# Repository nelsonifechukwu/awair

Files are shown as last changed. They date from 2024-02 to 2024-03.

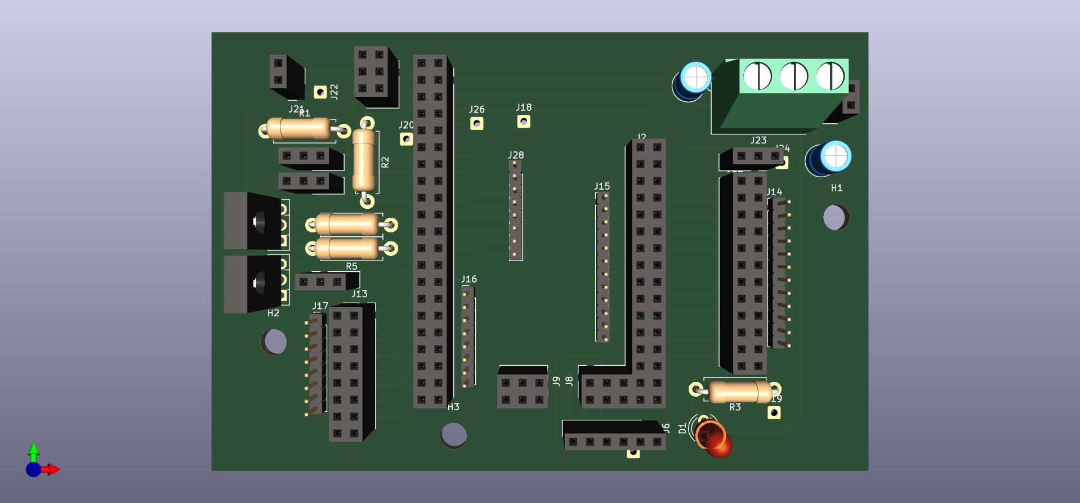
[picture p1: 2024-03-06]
Awair/CAD/Electrical Design/Awair.jpg

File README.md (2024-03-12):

# AWAIR

In Africa, the absence of an extensive meteorological device network has posed a significant challenge for environmental research, hindering accurate ground-truth data acquisition. This limitation affects various sectors, including government initiatives, urban planning, pollution control, etc.

Recognizing this gap, Awair emerges as a groundbreaking solution, offering an advanced, cloud-connected, real-time platform for environmental data. Awair aims to empower top universities, research labs, government agencies, and African industrial applications by providing accurate meteorological insights, facilitating informed decision-making, and sustainable solutions for environmental challenges.

Awair's data awareness, research, and analytics capabilities present a transformative approach to addressing the pressing issues related to the environment in the African context.



# Table of Content
- [Testing](#Testing)
  - [Input temperature data](#input-tph-data)
  - [Input airqo data](#input-airqo-data)
  - [Input wind data](#input-wind-data)
  - [Input location data](#input-location-data)
- [Hardware Design](#hardware-design)
  - [Electrical CAD](#electrical-cad)
  - [Mechanical CAD](#mechanical-cad)
  - [Embedded Software](#embedded-software)
 
# Testing 
- Register at [Awair](https://awair.onrender.com/)
- Create a Device using any of these ID:
<br> 
- Start [sending](#sending-data)  
- Go to the analytics section to view forecast and visualize your data

<h3> Sending Data </h3>
Your hardware should use the following endpoints to interact with the platform: 

### Input tph data

- **URL:** `/temp`
- **Method:** `POST`
- **Description:** Allows users to insert data.
- **Request Body:**
```
body request: {
    "uuid":"8254f02a-1c06-46f0-8382-66ad5be70cb6",
    "temperature": "20",
    "humidity":"50",
    "pressure": "80"
}
```

- **Response:**

```json
created
```

### Input airqo data

- **URL:** `/airqo`
- **Method:** `POST`
- **Description:** Allows users to insert data.
- **Request Body:**
```
body request: {
    "uuid":"8254f02a-1c06-46f0-8382-66ad5be70cb6",
    "pm2.5":"11.3",
    "pm10":"25",
    "co_index": 10
}
```

- **Response:**

```json
created
```

### Input wind data

- **URL:** `/wind`
- **Method:** `POST`
- **Description:** Allows users to insert data.
- **Request Body:**
```
body request: {
    "uuid": "8254f02a-1c06-46f0-8382-66ad5be70cb6",
    "wind-speed":"23",
    "wind-direction":"40"
}
```

- **Response:**

```json
created
```
### Input location data

- **URL:** `/location`
- **Method:** `POST`
- **Description:** Allows users to insert data.
- **Request Body:**
```
body request: {
    "uuid":"8254f02a-1c06-46f0-8382-66ad5be70cb6",
    "location": "0,40",
    "battery":"50",
    "signal": "80"
}
```

- **Response:**

```json
created
```

# Hardware Design
  <h3>Electrical CAD</h3> 
  
  <ins>Requirements: </ins>
  - Basic Electronics
  - Hardware Materials:
    - ESP32
    - SD Card Module & SD Card
    - Female Header Pins
    - DHT 22 Temperature Sensor
    - BMP180 Pressure Sensor
    - Sim 800l EVB GPS/GSM/GPRS sensor
    - CO2 sensor
    - Pm 2.5 & Pm 10 Air Quality Sensors
    - Batteries (4x 3.7v Lipo Batteries)
    - Wires
    - 2x 12-5v Buck Converters
     
 <ins>How To: </ins>
 - Download the CAD files from ```.Awair/CAD/Electrical Design```
 - Use a printing service like JLC PCB to print the PCB. Or, use a CNC to cut the designed sketch
 - Mount the parts as shown in the PCB Diagram.

<h3>Mechanical CAD</h3>

 <ins>Requirements: </ins>
 - Basic CAD skills
 - Basic 3d Printing
   
 <ins>How To: </ins>
 - Download the CAD files from ```.Awair/CAD/Mechanical Design```
 - Use a 3d printer to print the files (battery pack, cover, enclosure).

<h3>Embedded Software</h3>

<ins>How To:</ins>
 - After setting up the hardware, open the file ```Awair/Embedded Code``` using platformIDE
 - Edit your variable ```uuid``` with the uuid obtained after registration
 - Edit the variable ```API-key``` with the API-Key obtained from the web application after registration
 - Upload the code to the ESP32

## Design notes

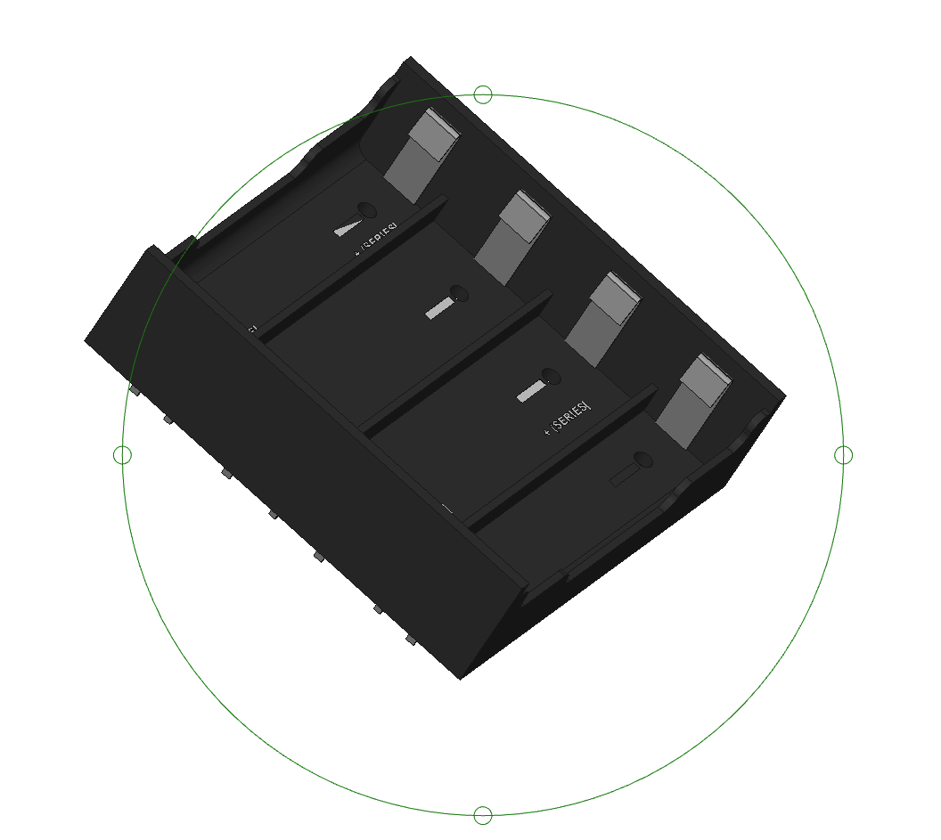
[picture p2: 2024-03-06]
Awair/CAD/Mechanical Design/Battery Pack.png

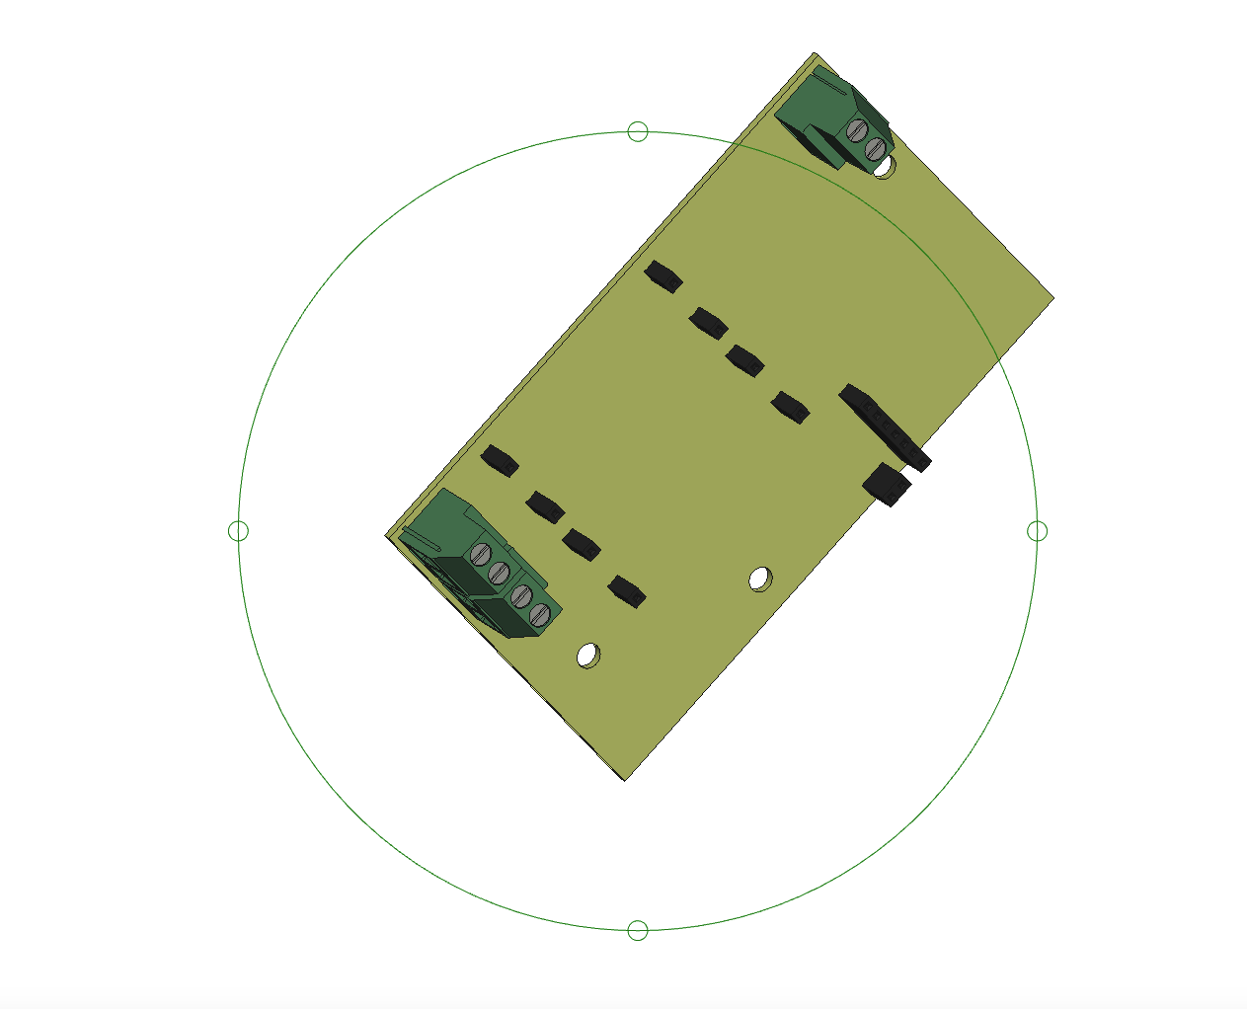
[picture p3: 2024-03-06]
Awair/CAD/Mechanical Design/PDB.png

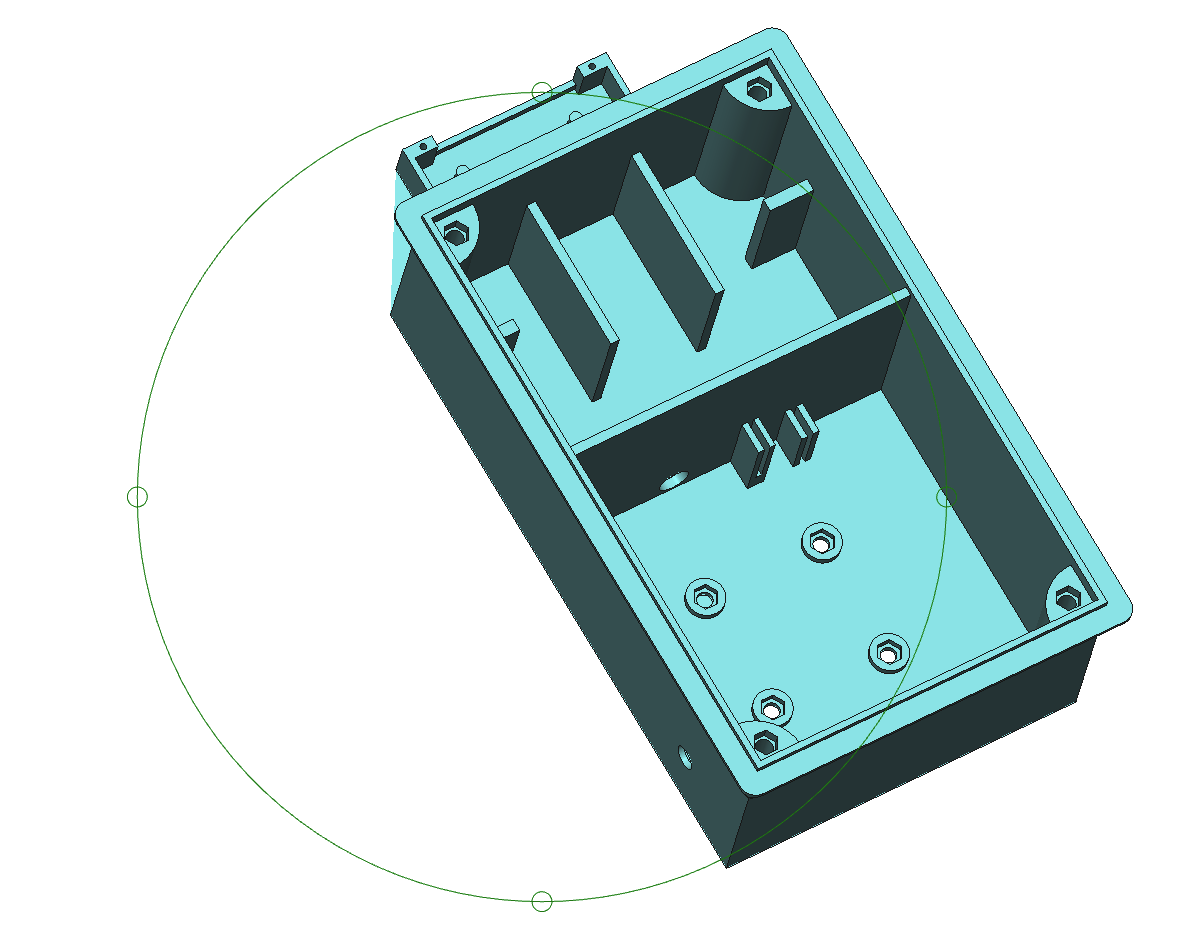
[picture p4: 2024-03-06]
Awair/CAD/Mechanical Design/Enclousure.png

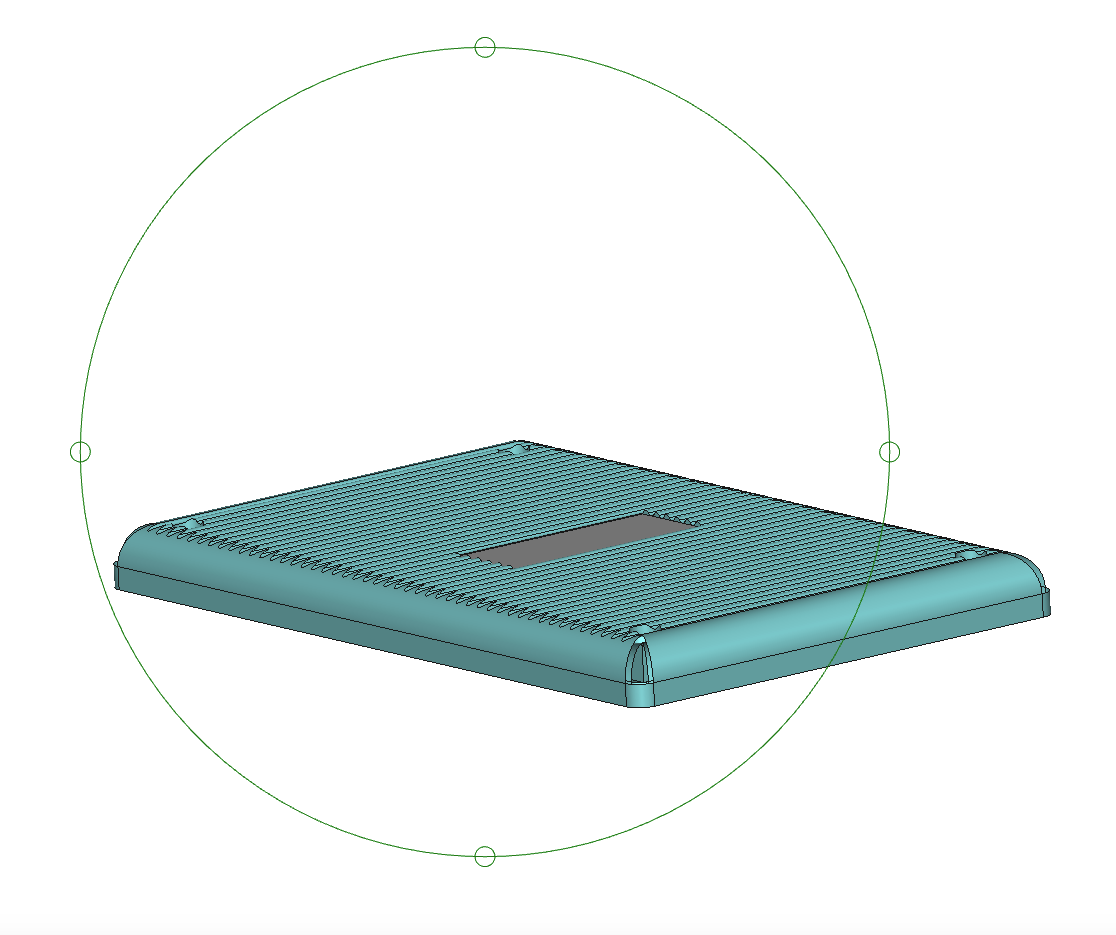
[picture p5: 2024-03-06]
Awair/CAD/Mechanical Design/Cover.png

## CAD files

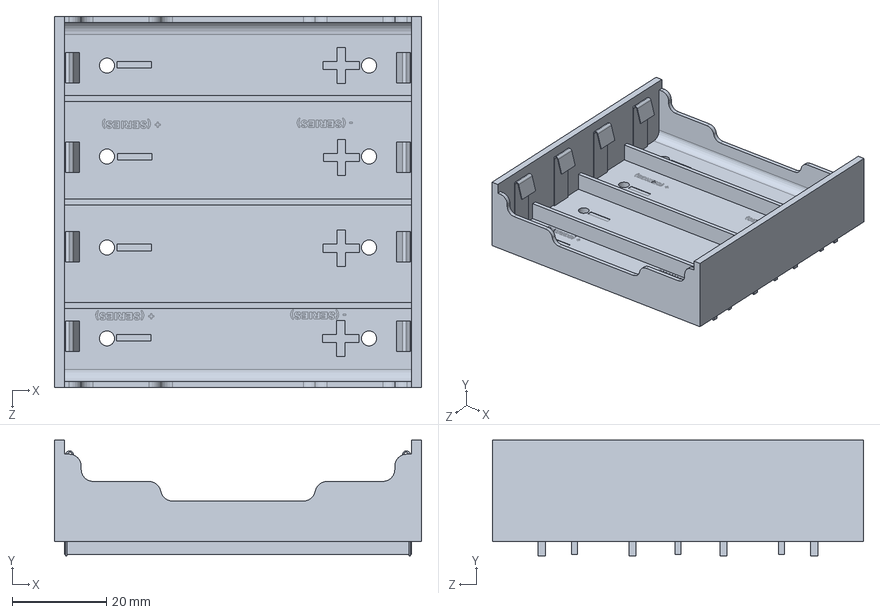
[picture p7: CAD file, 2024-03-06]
Awair/CAD/Mechanical Design/V2_BK-18650-Li-ion-4.SLDPRT
78.0 x 24.6 x 78.7 mm

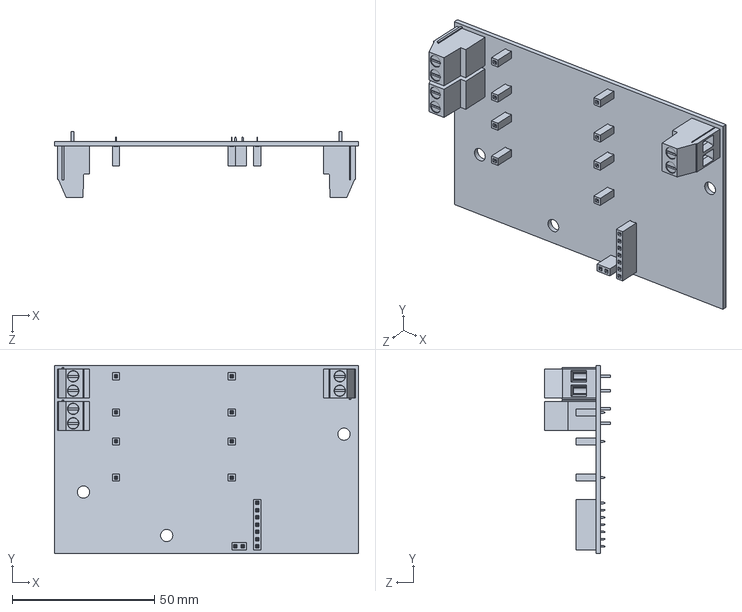
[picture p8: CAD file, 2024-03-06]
Awair/CAD/Mechanical Design/V2_Africo_P.SLDPRT
106.7 x 66.0 x 23.0 mm

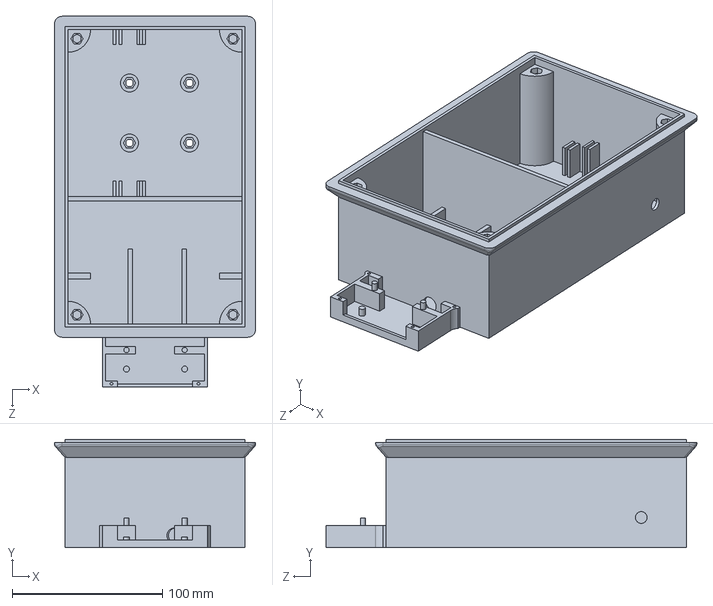
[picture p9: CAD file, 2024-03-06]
Awair/CAD/Mechanical Design/V2_Enclosure 2.SLDPRT
134.0 x 72.0 x 247.0 mm

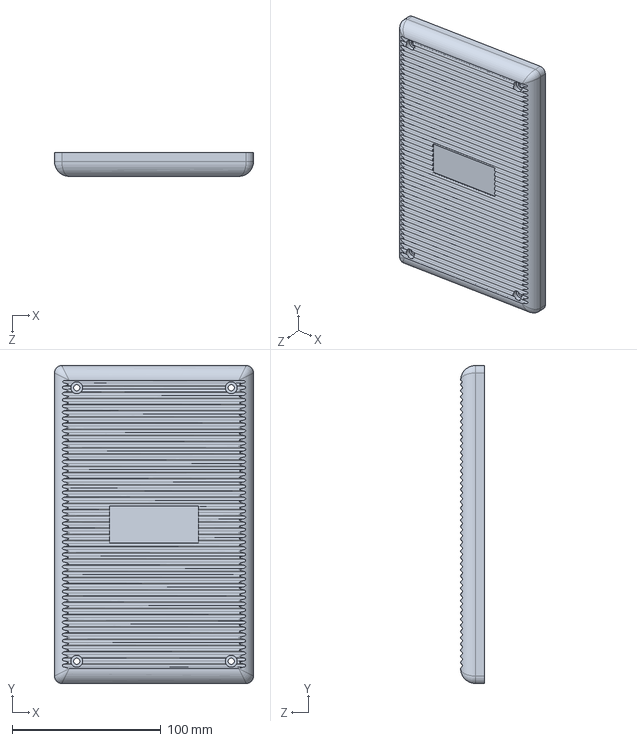
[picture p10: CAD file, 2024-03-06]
Awair/CAD/Mechanical Design/V2_Cover.SLDPRT
134.0 x 214.0 x 16.0 mm

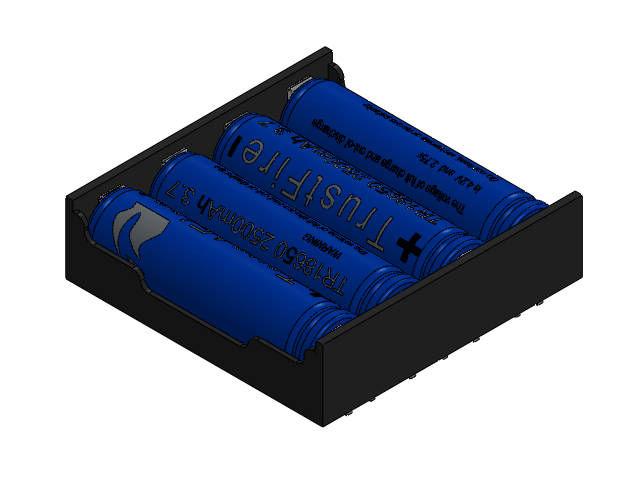
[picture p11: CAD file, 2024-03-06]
Awair/CAD/Mechanical Design/V2_battery pack.SLDASM
V2_BK-18650-Li-ion-4
V2_TR18650 x 4

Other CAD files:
Awair/CAD/Mechanical Design/V2_GSM ANTENNA.SLDPRT
Awair/CAD/Mechanical Design/V2_Enclosure 2.STL

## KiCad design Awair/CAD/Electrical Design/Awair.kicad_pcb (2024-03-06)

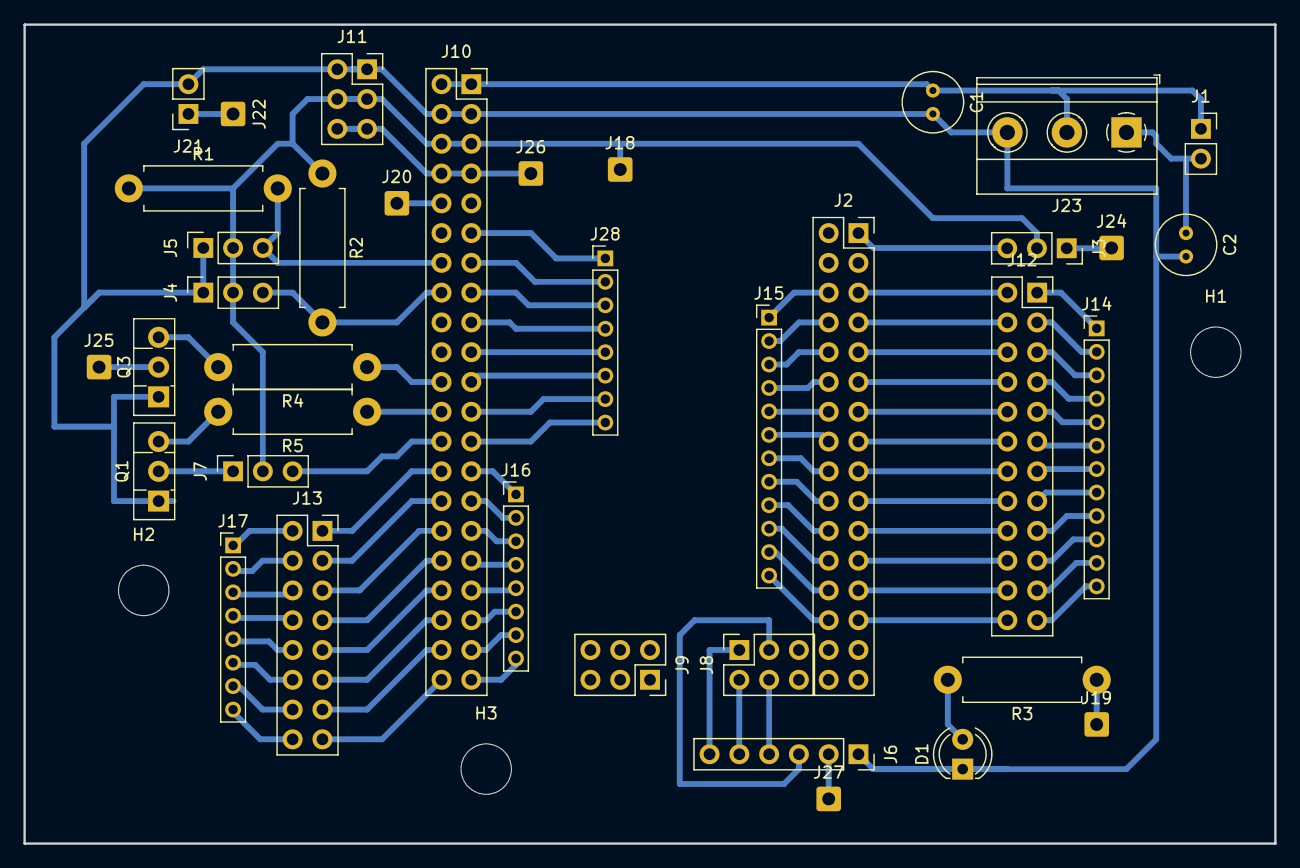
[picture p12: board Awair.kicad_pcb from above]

Board: 2 copper layers, 106.7 x 69.8 mm, 41 parts (0 on the bottom side), 69 nets.

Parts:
C1, C2: C; C_Radial_D5.0mm_H5.0mm_P2.00mm
D1: LED; LED_D4.0mm
H1, H2, H3: MountingHole; MountingHole_4.3mm_M4_DIN965
J1, J21: Conn_01x02_Pin; PinSocket_1x02_P2.54mm_Vertical
J2: Conn_02x16_Odd_Even; PinSocket_2x16_P2.54mm_Vertical
J3, J4, J5, J7: Conn_01x03_Pin; PinSocket_1x03_P2.54mm_Vertical
J6: Conn_01x06_Pin; PinSocket_1x06_P2.54mm_Vertical
J8, J9, J11: Conn_02x03_Odd_Even; PinSocket_2x03_P2.54mm_Vertical
J10: Conn_02x21_Odd_Even; PinSocket_2x21_P2.54mm_Vertical
J12: Conn_02x12_Odd_Even; PinSocket_2x12_P2.54mm_Vertical
J13: Conn_02x08_Odd_Even; PinSocket_2x08_P2.54mm_Vertical
J14, J15: Conn_01x12_Pin; PinHeader_1x12_P2.00mm_Vertical
J16, J17, J28: Conn_01x08_Pin; PinHeader_1x08_P2.00mm_Vertical
J18, J19, J20, J22, J24, J25, J26, J27: Conn_01x01_Pin; SolderWire-0.5sqmm_1x01_D0.9mm_OD2.1mm
J23: Screw_Terminal_01x03; TerminalBlock_Phoenix_MKDS-1,5-3-5.08_1x03_P5.08mm_Horizont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
Q1, Q3: BD135; TO-126-3_Vertical
R1, R2, R3: R; R_Axial_DIN0411_L9.9mm_D3.6mm_P12.70mm_Horizontal
R4, R5: 4.7k; R_Axial_DIN0411_L9.9mm_D3.6mm_P12.70mm_Horizontal

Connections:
+3.3V: J6.2, J10.7, J10.8, J11.5, J11.6, J26.1, J27.1
+5V: J3.2, J4.2, J5.2, J7.2, J10.5, J10.6, J11.3, J11.4, J18.1, J19.1, R1.1, R2.1, R3.1
A4: J2.5, J12.2
A5: J2.6, J12.1, J14.1, J15.1
A6: J2.7, J12.4
A7: J2.8, J12.3, J14.2, J15.2
A8: J2.9, J12.6
A9: J2.10, J12.5, J14.3, J15.3
A10: J2.11, J12.8
A11: J2.12, J12.7, J14.4, J15.4
A12: J2.13, J12.10
A13: J2.14, J12.9, J14.5, J15.5
A14: J2.15, J12.12
A15: J2.16, J12.11, J14.6, J15.6
CS: J6.6, J8.1
D16: J10.27, J13.2, J16.1, J17.1
D17: J10.28, J13.1
D18: J10.29, J13.4, J16.2, J17.2
D19: J10.30, J13.3
D20: J10.31, J13.6, J16.3, J17.3
D21: J10.32, J13.5
D22: J10.33, J13.8, J16.4, J17.4
D23: J10.34, J13.7
D24: J10.35, J13.10, J16.5, J17.5
D25: J10.36, J13.9
D26: J10.37, J13.12, J16.6, J17.6
D27: J10.38, J13.11
D28: J10.39, J13.14, J16.7, J17.7
D29: J10.40, J13.13
D30: J10.41, J13.16, J16.8, J17.8
D31: J10.42, J13.15
D32: J2.17, J12.14
D33: J2.18, J12.13, J14.7, J15.7
D34: J2.19, J12.16
D35: J2.20, J12.15, J14.8, J15.8
D36: J2.21, J12.18
D37: J2.22, J12.17, J14.9, J15.9
D38: J2.23, J12.20
D39: J2.24, J12.19, J14.10, J15.10
D40: J2.25, J12.22
D41: J2.26, J12.21, J14.11, J15.11
D42: J2.27, J12.24
D43: J2.28, J12.23, J14.12, J15.12
DHT11: J5.3, J10.14, R1.2
GN1: J3.1, J24.1, J25.1, Q3.2 (C)
GN2: J7.1, Q1.2 (C)
GND: C1.2, C2.2, D1.1 (K), J4.1, J5.1, J6.1, J10.3, J10.4, J11.1, J11.2, J21.2, J23.3, Q1.1 (E), Q3.1 (E)
GPS: J7.3, J10.26
MISO: J6.4, J8.4
MOSI: J6.3, J8.3
MQ7: J2.1, J3.3
unnamed: D1.2 (A), R3.2
unnamed: J10.11, J28.1
unnamed: J10.13, J28.2
unnamed: J10.15, J28.3
unnamed: J10.17, J28.4
unnamed: J10.19, J28.5
unnamed: J10.21, J28.6
unnamed: J10.23, J28.7
unnamed: J10.25, J28.8
unnamed: Q1.3 (B), R5.2
unnamed: Q3.3 (B), R4.2
RESET: J10.10, J20.1, J21.1, J22.1
SCK: J6.5, J8.2
T1: J10.22, R4.1
T2: J10.24, R5.1
Temp: J4.3, J10.16, R2.2
VIN: C1.1, J1.1, J10.1, J10.2, J23.2
VIN_3V3: C2.1, J1.2, J23.1

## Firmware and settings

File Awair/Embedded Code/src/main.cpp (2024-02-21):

#include <main.hpp>
#include <vector.h>

/* Pin definition start*/
#define status_led 13

/*end of pin definition*/

#define log_time_interval 10000 // 10s


long ct,task1,task2,task3,task4;
char c;
GPS_Data gps_data;
Sensors_data All_sensors;
Vector<int> list;

HardwareSerial* GPS_Serial = &Serial2;

void setup() {
  pinMode(status_led,OUTPUT);
  // Open serial communications and wait for port to open:
  Serial.begin(9600);
  GPS_Serial->begin(9600);
  sensors_init();
  delay(4000);
  logger_begin();
}

int rx_complete;
void loop() {
  ct = millis();
  if((ct-task1)>1000){
    digitalWrite(status_led,!digitalRead(status_led));
    get_temperature(&All_sensors.temperature);
    get_humidity(&All_sensors.humidity);
    Serial.print("Temp: "+ All_sensors.temperature);
    Serial.println("\tR.H: "+All_sensors.humidity);
    task1 = ct;
  }

  if((ct-task2)> log_time_interval){
    All_sensors.longitude = gps_data._long;
    All_sensors.latitude = gps_data._lat;
    All_sensors.time = gps_data.time;
    All_sensors.date = gps_data.date;
    All_sensors.wind_speed = gps_data.speed;
    All_sensors.wind_direction = (String)gps_data.direction_NS;
    get_air_quality(&All_sensors.air_quality);
    get_CO2(&All_sensors.CO2);
    get_wind_speed(&All_sensors.wind_speed);
    get_wind_dir(&All_sensors.wind_direction);
    log_data(All_sensors);
    task2 = ct;
  }
  

  if(rx_complete==GPRMC){
    // Serial.print("Lat: "+String(gps_data._lat));
    // Serial.print(" Lon: "+String(gps_data._long));
    // Serial.print(" Time: "+String(gps_data.time));
    // Serial.print(" Date: "+String(gps_data.date));
    // Serial.println(" Speed: "+String(gps_data.speed));

    rx_complete = false;
  }

  while(GPS_Serial->available()){
    c = (char)GPS_Serial->read();
    //Serial.print(c);
    rx_complete = Process_GPS_Data(c,&gps_data,GPRMC);
  }
}

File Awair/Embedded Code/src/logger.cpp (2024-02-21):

#include <logger.h>


File myFile;
String file_name;
Vector<char> image;

void logger_begin(){
    //EEPROM.write(fileN0_address,0); // for setup ONLY

    int fileN0 = EEPROM.read(fileN0_address);
    Serial.println("initializing SDcard"); 
    if (!SD.begin(SD_CS_pin)){
        Serial.println("initialization failed!");
        return;
    }
    Serial.println("initialization done."); 
  
    if(SD.exists("DATA_"+String(fileN0)+".csv")){
      fileN0++;
      // update file Number
      EEPROM.write(fileN0_address,fileN0);
    }
    file_name = "DATA_"+String(fileN0)+".csv";

    myFile = SD.open(file_name, FILE_WRITE);

    // if the file opened okay, write to it:
    if (myFile) {
        myFile.print("Date,");
        myFile.print("Time,");
        myFile.print("Longitude,");
        myFile.print("Latitude,");
        myFile.print("Temperature,");
        myFile.print("Humidity,");
        myFile.print("Rain fall,");
        myFile.print("CO2,");
        myFile.print("Air quality,");
        myFile.print("Wind Speed,");
        myFile.println("Wind Direction");
        // close the file:
        myFile.close();
        Serial.println("Data saved to "+file_name);
    } else {
        // if the file didn't open, print an error:
        Serial.println("error opening "+file_name);
    }
    
}

void log_data(Sensors_data data){
  myFile = SD.open(file_name, FILE_WRITE);

  // if the file opened okay, write to it:
  if (myFile) {
    myFile.print(data.date);
    myFile.print(",");
    myFile.print(data.time);
    myFile.print(",");
    myFile.print(data.longitude);
    myFile.print(",");
    myFile.print(data.latitude);
    myFile.print(",");
    myFile.print(data.temperature);
    myFile.print(",");
    myFile.print(data.humidity);
    myFile.print(",");
    myFile.print(data.rainfall);
    myFile.print(",");
    myFile.print(data.CO2);
    myFile.print(",");
    myFile.print(data.air_quality);
    myFile.print(",");
    myFile.print(data.wind_speed);
    myFile.print(",");
    myFile.println(data.wind_direction);

    // close the file:
    myFile.close();
    Serial.println("Data saved to "+file_name);
  } else {
    // if the file didn't open, print an error:
    Serial.println("error opening "+file_name);
  }
}

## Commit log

2024-03-06 added CAD files
    [Awair.kicad_pcb, Awair.kicad_sch, V2_Africo_P.SLDPRT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]
2024-03-07 fixed button interaction with scroll card
2024-03-12 updated list table style; updated device card style
2024-03-22 updated analytics styling; updated analytics popover; updated analytics color scheme; updated analytics proportionate layout; added flask-cache to utilize memoization to improve server interaction sp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
